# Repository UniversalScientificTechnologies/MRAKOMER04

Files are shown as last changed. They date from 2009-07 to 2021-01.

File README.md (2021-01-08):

# MRAKOMER04B (MRAKOMER 4.0 equivalent)

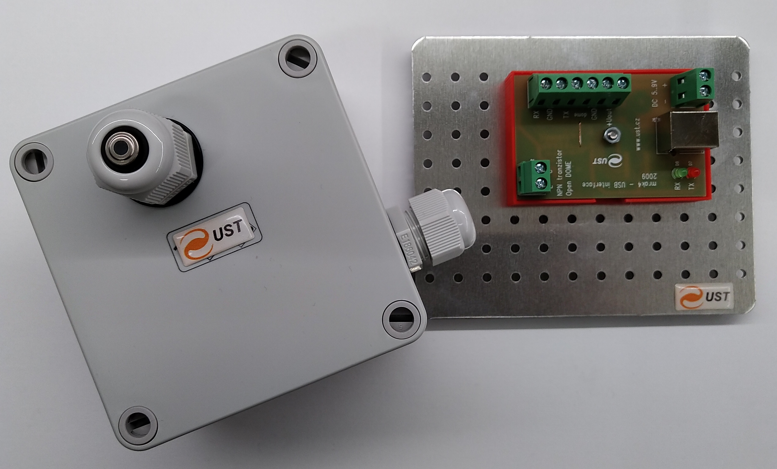
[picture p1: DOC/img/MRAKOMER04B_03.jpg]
Set of MRAKOMER04 internal and outdoor units


### Documentation:

  - [Czech](/DOC/MRAKOMER04B.cs.pdf)
  - [English](/DOC/MRAKOMER04B.en.pdf)

### Parameters:

  - Temperature measurement accuracy 1 °C  
  - Dual zone measurement in FOV 40 deg for each zone
  - Measurement period 1 second
  - Measurement temperature range -65 to +40 °C
  - Operating temperature range -30 to +40 °C

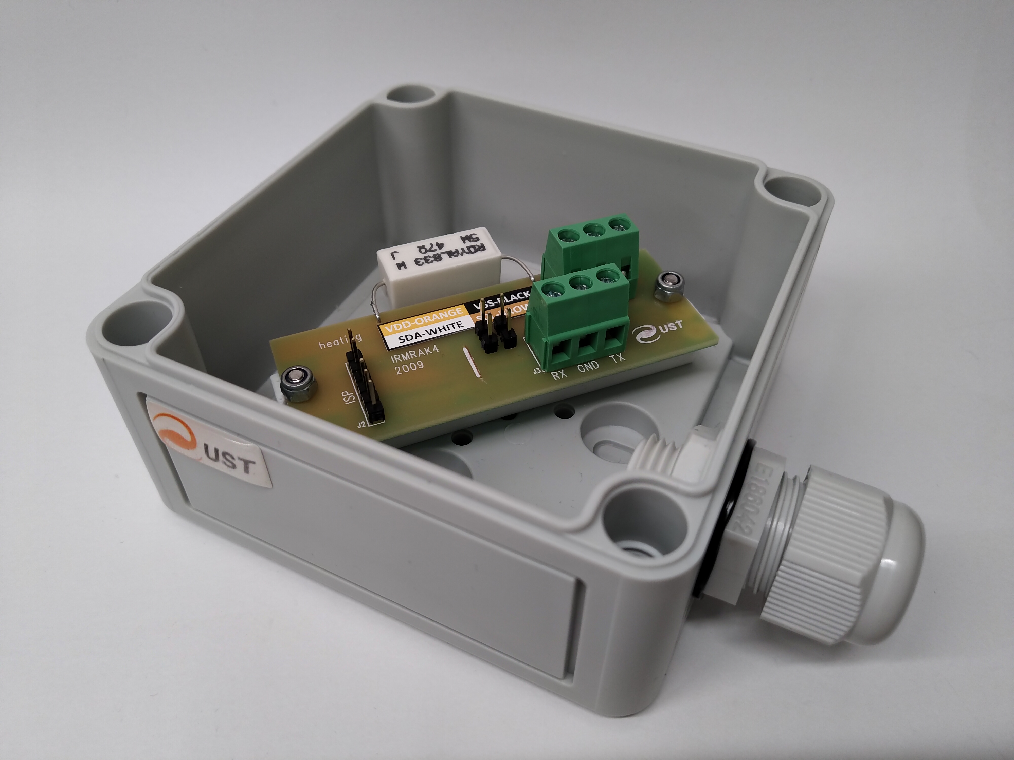
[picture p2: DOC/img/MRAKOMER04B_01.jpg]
MRAKOMER04 external unit opened


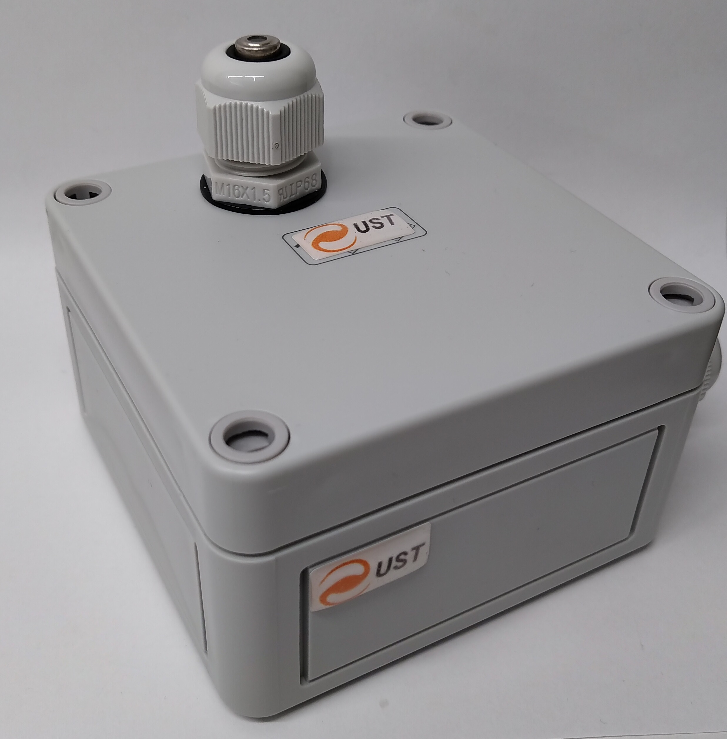
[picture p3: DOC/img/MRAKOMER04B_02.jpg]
MRAKOMER04 external unit


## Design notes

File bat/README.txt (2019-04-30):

h.sh -- heating activation
logger.sh -- simple logging script 
plotMM.plt -- gnuplot data plot script
uf_new.sh -- firmware upload script for new MRAKOMER4 only with bootloader
uf_upload.sh -- firmware upload script

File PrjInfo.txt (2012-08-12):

//
// This is a project description file.
//

[InfoShortDescription.en]
Mrakoměr4 (Clouds sensor) 

[InfoShortDescription.cs]
Mrakoměr4
  
[InfoLongDescription.en]
This is a device for measurement the clouds coverage. This device is especially constructed for protection of robotics telescopes against rain and snow. This is a second generation without moving parts.

[InfoLongDescription.cs]
Přístroj je navržen pro detekci kritického lokálního množství vody v atmosféře jako součást robotických dalekohledů. Tento model je druhou vylepšenou generací bez pohyblivých částí.

[InfoBuyUST]
http://www.ust.cz/shop/product_info.php?cPath=29&products_id=43

[End]

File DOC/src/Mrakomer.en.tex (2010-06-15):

\documentclass[10pt,a4paper]{article}
\usepackage[utf8]{inputenc}
\usepackage[english]{babel}
\usepackage{graphicx}
\usepackage{amsmath}
\usepackage{amsfonts}
\usepackage{amssymb}
%\usepackage{fancyhdr}

%\pagestyle{fancy}
%\fancyhead{}
%\fancyfoot{}

\title{MRAKOMĚR}
\author{Kaklik}

%\fancyhead[C]{\begin{tabular}\hline \title nejaky text \hline \end{tabular}}
%\fancyfoot[L] {/\today / \author / www.mlab.cz}
%\fancyfoot[R]{\thepage }

\begin{document}

\maketitle
\tableofcontents

\newpage

\section{Why you need the MRAKOMĚR?}
MRAKOMĚR is a cloud meter sensor suitable for protect maintenance free telescopes against rain and snow. The MRAKOMĚR function is command cupola or other telescope housing to close if MRAKOMĚR see a cloudy sky. 

\section{Measuring principle}
MRAKOMĚR act as a IR thermometer because clouds reflecting a much IR radiation. Then the measuring unit catch the reflected radiation and count it's intensity to determine how much cloudy sky is above the telescope. If a level of water vapor is over the copula is ordered to close. 

\section{Technical realization}
The thermopile sensor is directed  to the zenith and integrate radiation flux over $90^\circ$ angle. However there must not be any terrestrial (atmospheric  heated) object in viewing  angle because they can cause malfunction by it's IR radiation.        

The thermopile sensor in MRAKOMĚR  is covered by small and thin HDPE cupola which protect the senor itself against atmospheric events. The HDPE material have good transparency in IR but sometimes there can be a condensate water. As solution for this problem (condensate water is resolved as cloudy) there is a 2W heating resistor in MRAKOMĚR case which is suitable to stop water condensing on thermopile sensor housing or it can melt the accidental ice too. 

MRAKOMĚR is connected to telescope computer (IBM PC ) over USB interface  board where is standard RS232 port emulated. Also there is a option of direct RS232 connection if it is desired by user. But in this mode an external power source is needed. And in addition there is an optocoupled output channel which is activated in cloudy or if the computer get frozen.

Sensor and interface part of the MRAKOMĚR is connected together trough  cable connection up to 100m long (the electronics is protected by some transils against damage by electric surge on stormy locations)

\section{Communication protocol}
If MRAKOMĚR is plugged to the computer it communicate by speed 2400 baud (8N1) and every second transmit an message such as: 

\begin{verbatim}
$M4.1 2866 2383 -63 17 15 *5A
\end{verbatim}

Where MX.X is the version and revision 2866 is a number of measuring (0 to 65535). 2383 is a temperature in sensor case (23.83 $^\circ$C). And -63 meaning that sky "have" -0.63 $^\circ$C. Last two numbers before star is number of seconds to turn off the heating and to close the cupola (this counter will resets if appropriate command is received). After a star symbol is hexadecimal value of XOR of symbols between \verb+$+ and *.

\begin{table}[htbp]
\begin{center}
\begin{tabular}{|c|c|}
\hline  h & turn on heating for 20s \\ 
\hline  c & turn off heating  \\ 
\hline  o & open cupola \\ 
\hline  x & open cupola and turn on heating \\ 
\hline  l & close cupola \\ 
\hline  i & list version and some help (only if cupola is closed)  \\ 
\hline  r & turn on periodical messaging every second \\ 
\hline  s & turn off periodical messaging \\ 
\hline  u & switch MRAKOMĚR to firmware update mode \\ 
\hline 
\end{tabular}
\caption{MRAKOMĚR commands}
\end{center}

\end{table}

\section{Conclusions}
MRAKOMĚR is device suitable to perfectly protect telescope. But sometimes may detect cloudy sky even if it clear it is happened when water vapor condensate on sensor housing. It can be prevented by turn on heating if weather conditions is near to condensate point. 

\end{document}

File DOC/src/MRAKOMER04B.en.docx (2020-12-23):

MRAKOMER04B

## MRAKOMER04B is a device for measuring clouds

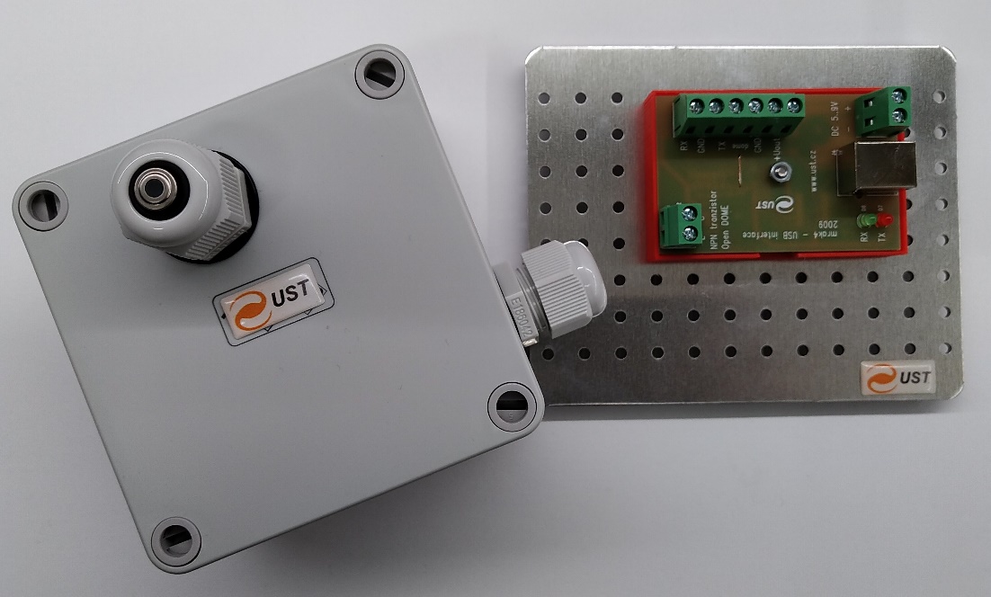
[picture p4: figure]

# 1. Why you need the MRAKOMER04B?

MRAKOMER04B is a cloud meter sensor suitable for protect maintenance free telescopes against rain and snow. The MRAKOMER04B function is command cupola or other telescope housing to close if MRAKOMER04B see a cloudy sky.

# 2. Measuring principle

MRAKOMER04B act as a IR thermometer because clouds reecting a much IR radiation. Then the measuring unit catch the re ected radiation and count it's intensity to determine how much cloudy sky is above the telescope. If a level of water vapor is over the copula is ordered to close.

# 3. Technical realization

The thermopile sensor is directed to the zenith and integrate radiation flux over 90 angle. However there must not be any terrestrial (atmospheric heated) object in viewing angle because they can cause malfunction by it's IR radiation.

The thermopile sensor in MRAKOMER04B is covered by small and thin HDPE cupola which protect the senor itself against atmospheric events. The HDPE material have good transparency in IR but sometimes there can be a condensate water. As solution for this problem (condensate water is resolved as cloudy) there is a 2W heating resistor in MRAKOMER04B case which is suitable to stop water condensing on thermopile sensor housing or it can melt the accidental ice too.

MRAKOMER04B is connected to telescope computer (IBM PC ) over USB interface board where is standard RS232 port emulated. Also there is a option of direct RS232 connection if it is desired by user. But in this mode an external power source is needed. And in addition there is an optocoupled output channel which is activated in cloudy or if the computer get frozen.

Sensor and interface part of the MRAKOMER04B is connected together trough cable connection up to 100m long (the electronics is protected by some transils against damage by electric surge on stormy locations)

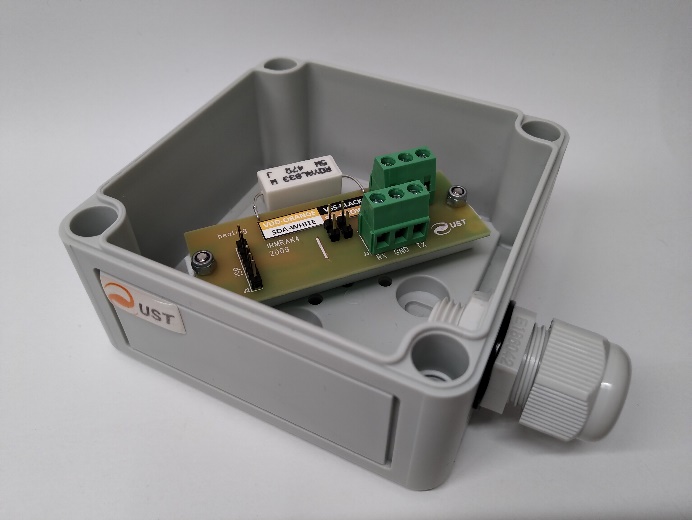
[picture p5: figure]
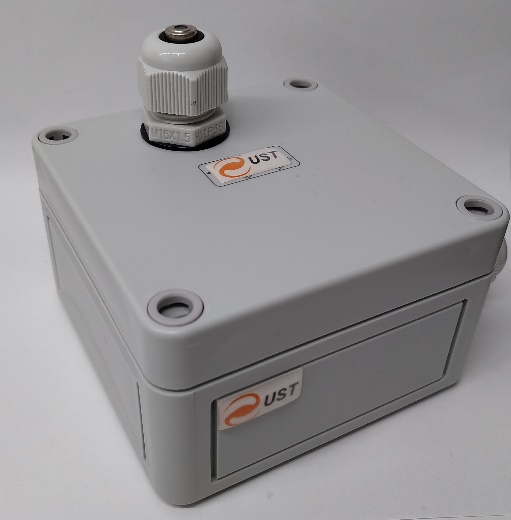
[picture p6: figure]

# 4. Communication protocol

If MRAKOMER04B is plugged to the computer it communicate by speed 2400 baud (8N1) and every second transmit an message such as:

$M4.1 2866 2383 -63 17 15 *5A

Where MX.X is the version and revision 2866 is a number of measuring (0 to 65535). 2383 is a temperature in sensor case (23.83 C). And -63 meaning that sky "have" -0.63 C. Last two numbers before star is number of seconds to turn o the heating and to close the cupola (this counter will resets if appropriate command is received). After a star symbol is hexadecimal value of XOR of symbols between $ and *.

MRAKOMER04B commands:

h turn on heating for 20s

c turn o heating

o open cupola

x open cupola and turn on heating

l close cupola

i list version and some help (only if cupola is closed)

r turn on periodical messaging every second

s turn o periodical messaging

u switch MRAKOMER04B to firmware update mode

# 5. Conclusions

MRAKOMER04B is device suitable to perfectly protect telescope. But sometimes may detect cloudy sky even if it clear it is happened when water vapor con-densate on sensor housing. It can be prevented by turn on heating if weather conditions is near to condensate point.

MRAKOMER04B.en | 2020-12-23 | http://www.ust.cz 1 / 6

www.ust.cz

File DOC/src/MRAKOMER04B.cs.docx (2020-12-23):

MRAKOMER04B

## Mrakoměr je přístroj pro měření oblačnosti.


# 1. Co vlastně mrakoměr měří a proč

Popisované zařízení bylo zkonstruováno pro ochranu robotických bezobslužných dalekohledů před deštěm. Cílem bylo vyvinout přístroj, který bude včas varovat před blížícím se deštěm/sněhem a jeho varování následně vyvolá povel pro zavření domečku dalekohledu. Předpokládá se při tom, že déšť/sníh padá z mraků, které jsou vidět v okolí dalekohledu.

# 2. Princip měření

Mrakoměr je vlastně teploměr, který měří průměrnou teplotu celého sloupce atmosféry. K průměrné teplotě atmosféry nejvíce přispívají nižší husté vrstvy a v nich nejvíce voda, která je obsažena v troposféře. Vzhledem k tomu, že mraky jsou z vody, jejich přítomnost výrazně ovlivňuje průměrnou teplotu.

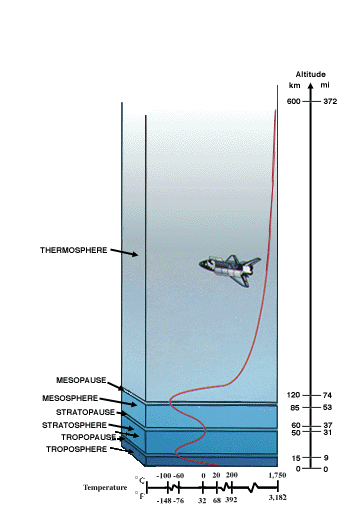
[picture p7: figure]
[Picture of atmosphere layers]

Mrakoměr měří teplotu použitím termoelektrického (Seebeckova) jevu.

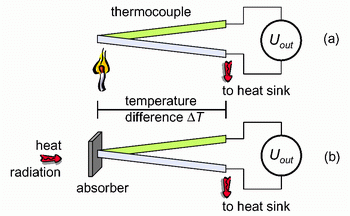
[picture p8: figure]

Spojíme-li dva nesourodé vodiče nebo polovodiče a jeden jejich konec ohříváme a druhý ochlazujeme, vytvoříme článek, který generuje napětí. Pro správné pochopení principu Mrakoměru je důležité si uvědomit, že takovýto článek neměří teplotu, ale tepelný tok.

V Mrakoměru 4 je použit Thermopile senzor. Thermopile senzor je vlastně baterie termočlánků zapojených do série. Teplé konce jsou překryty terčíkem, který absorbuje tepelné záření. Studené konce jsou připojeny na křemíkový nosič. Aby se maximálně snížil přestup tepla křemíkem, je křemíkový nosič ztenčen na tenkou membránu. Teplota křemíku na studeném konci je měřena teplotním senzorem, což umožňuje tepelný tok vztáhnout k absolutní teplotě nosiče a tím určit teplotu dopadajícího IR záření.

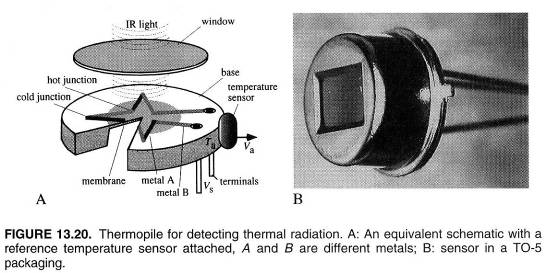
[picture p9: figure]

## 2.1. Popis činnosti

Thermopile senzor se zorným úhlem cca 90° je nasměrován do zenitu a integruje teplotu přes celé zorné pole. Z toho důvodu nesmí být v jeho zorném poli pozemní předměty, jejichž tepelné vyzařování by ovlivňovalo měření.

Thermopile senzor je v Mrakoměru překryt kopulkou z HDPE, která je dobře propustná pro IR záření v okolí 5μm. HDPE je nesmáčivý a tak voda na jeho povrchu v případě deště nebo rosy vytvoří kapky, které pak snadněji opustí zorné pole. Pokud je na kopulce voda, Mrakoměr jí vyhodnotí jako mraky. Uvnitř Mrakoměru je topné těleso o výkonu asi 2W, které slouží k rozpuštění sněhu nebo ledu na kopulce a případně k odpaření rosy.

Mrakoměr se k řídícímu počítači dalekohledu (IBM PC) připojuje pomocí rozhraní USB přes které se provádí emulace RS232. Rozhraní RS232 se používá pro spojení mezi stanicí s thermopile senzorem (horní) a stanicí, kde je převodník mezi USB a RS232 (dolní). Protože rozhraní RS232 umožňuje připojit mezi obě stanice poměrně dlouhé vedení (až 100m) je z tohoto vedení sváděno případné naindukované napětí pomocí transilů.

V dolní stanici je ještě umístěn optočlen, pomocí kterého je možné předat dvoustavový signál z řídícího počítače do zařízení pro otevírání/zavírání kopule dalekohledu. Tento komunikační kanál je díky optočlenu galvanicky oddělen od řídícího systému kopule a je zajištěno, že při poškození Mrakoměru, nebo pokud řídící počítač dalekohledu nepožádá v pravidelném intervalu o otevření kopule, dojde k překlopení do stavu zavřeno.


Pokud se Mrakoměr zapojí do počítače, tak komunikuje rychlostí 2400 baud (8N1) a každou sekundu pošle zprávu, která vypadá například takto:

$M4.1 2866 2383 -63 17 15 *5A

Což znamená:

Verze firmware 4, revize 1. Měření číslo 2866 (opakuje se v rozsahu 0 až 65535); teplota pouzdra 23.83°C; teplota oblohy −0.63°C; 17 znamená, že zbývá 17s do vypnutí topení (0 znamená, že se netopí); 15 znamená 15s do zavření kopule (0 = zavřená kopule). Za * je kontrolní součet znaků mezi $ a * (XOR). Konkrétní hodnoty jsem si zde vymyslel.

Mrakoměr 4 reaguje na tyto příkazy:

h zapne topení na 20s

c vypne topení

o otevře kopuli na 20s

x otevře kopuli a zapne topení, oboje na 20s

l zavře kopuli

i vypíše verzi a nápovědu k výstupu (pouze, pokud je zavřena kopule)

r zapne periodický výpis každou sekundu

s vypne periodický výpis

u update firmware

Pozn.: Je zakázáno posílat do Mrakoměru příkazy častěji, než jednou za 1s. Nic se ale nestane, pokud do něj něco pošlete častěji, ale stejně pak dostanete odpověď na další příkaz až za 1s a navíc si Mrakoměr pamatuje poslední 3 příkazy! Vyzkoušejte si to v terminálu.

Význam LED v dolní stanici/krabičce:

Zelená - něco poslal Mrakoměr do PC (bliká pouze, pokud někdo/něco odebírá data z Mrakoměru, pokud neodebírá, tak bliká pouze do doby, než se zaplní buffery (cca 18 zpráv od Mrakoměru)) Červená - něco poslalo PCčko do Mrakoměru

Na optočlen pro ovládání kopule je možné připojit cokoli, co je na maximálně 300V a 100mA. Když to přeženete, tak optron vyhoří a začnete od píky. Svorkovnice, na kterou se připojuje domeček, je označena, že se na ní připojuje domeček. Pozor na polaritu! GND (zem) není propojena se zemí Mrakoměru. Takže se nemůže nic stát, stát, stát,...

Horní krabičku s čidlem raději nerozebírejte. Pokud ji rozeberete, tak vyjměte pytlík se silikagelem a reaktivujte ho při 150°C.

## 2.2. Update firmware

Mrakoměr 4 umožňuje update jeho firmware, aniž byste ho museli sundat ze střechy. Po zapnutí do USB portu čeká cca 50s na znaky „uf“. Pokud se do té doby do něj pošle něco jiného, začne měřit. Pokud se pošle „uf“, tak očekává HEX soubor s novým firmware. HEX soubor musí být upraven tak, že na konci každé řádky musí být přidán dostatečný počet (cca 20) výplňových znaků (např. „x“), které poskytnou Mrakoměru čas na vypálení jedné řádky kódu. Je to z důvodu, aby se nemusel používat v komunikaci handshake nebo specielní software pro výměnu firmware. Takto se dá nový firmware nahrát z terminálu a to i na dálku. Pokud se nový firmware nepodaří nahrát, je sice starý firmware přepsán a nefunguje, ale Mrakoměr opět bude čekat na znaky „uf“ a umožní vám nový pokus o přepsání firmware. Pokud odstraníte chybu (ta bude zřejmě ve vašem programu) a dáte na modlení, tak se vám podaří nahrát nový firmware.

## 2.3. Dosažené výsledky a omezení konstrukce

Popisované řešení dokáže spolehlivě detekovat oblačnost. Může se ovšem stát, že dojde k falešné detekci, pokud je stav okolního vzduchu blízký rosnému bodu a na kopulce zkondenzuje voda. Tomuto jevu můžeme předejít včasnou aktivací vyhřívání Mrakoměru.

Mrakoměr byl vyvinut pro potřeby dalekohledů s řídícím systémem RTS2. Proto jeho firmware funguje tak, jak funguje.

Mrakoměr je „Open Hardware“. To znamená, že je k dispozici plně dokumentované elektrické zapojení, výkresy plošných spojů a zdrojové kódy firmware. Můžete si tedy Mrakoměr sami vyrobit nebo dle libosti upravit To neznamená, že vám ho nepomůžeme vyrobit nebo pro vás neuděláme vylepšení, která budete potřebovat, když nás poprosíte, ovšem to už za peníze (to by nám jinak doma neprošlo ).

MRAKOMER04B.cs | 2020-12-23 | http://www.ust.cz 1 / 6

www.ust.cz

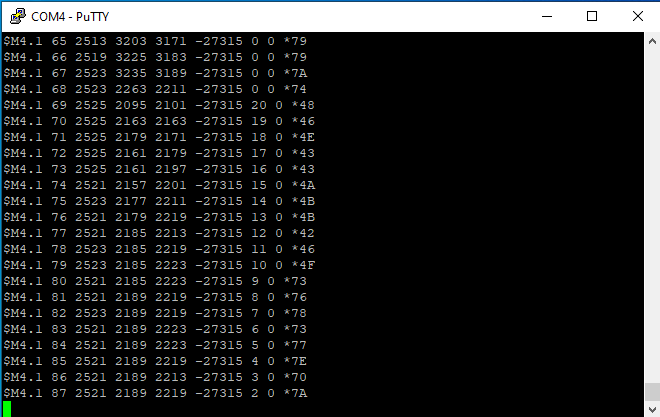
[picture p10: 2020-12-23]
DOC/img/MRAKOMER04B_RS_vypis.png

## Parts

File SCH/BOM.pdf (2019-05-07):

seznam součástek USB_PART_IRMRAK4 , IRMRAK4

USB_PART_IRMRAK4

Quantity | Reference | Part | PCB Footprint

kondenzátory
| 2 C1,C2 | 1u | C0805
| 8 C3,C5,C6,C7,C8,C9,C10,C11 | 100nF | C0805
| 1 C4 | 10uF/10V | C0805
diody
| 1 D1 | BAR43SSMD | SOT23
| 1 D2 | 15MQ040N | SMB
4 D3,D4,D5,D6 | P6SMBJ15CA (obousmerny) SMB
1 D7 | LED3mm_RED | 01. 03
1 D8 | LED3mm_GREEN | 01. 03
mechanika
| 1 J1 | LOAD_POWER | ARK210/2
| 1 J2 | DOME | ARK210/2
| 1 J3 | POWER | ARK210/3
| 1 J4 | USB_B_01 | USB_B_01
| 1 J5 | RS232 | ARK210/3
| 4 M1 | HOLE_M3 | HOLE_M3
optočlen
| 1 Q1 | TLP127-SMD | MFSOP6
tranzistory
| 1 Q2 | BC817SMD | SOT23
odpory
| 1 R1 | 150 | R0805
| 1 R2 | 180 | R0805
| 2 R5,R3 | 10k | R0805
| 1 R4 | 4k7 | R0805
| 2 R6,R7 | 270 | R0805
IO
| 1 U1 | FT232RL | SSO28_210
| 1 U2 | MAX232SMD/ST232ACD | SO16_150

IRMRAK4

Quantity | Reference | Part | PCB Footprint

kondenzátory
9 C1,C2,C3,C4,C5,C6,C7,C9,C11 100nF | C0805
| 1 C8 | 10u/16V | ELYTB
| 1 C10 | 10u/10V_tantal | ELYTA
diody
4 D1,D2,D3,D5 | P6SMBJ15CA (obousmerny) SMB
| 1 D4 | 15MQ040N | SMB
mechanika
| 1 J2 | PIC_ISP | PIC_ISP
| 1 J3 | RS232 | ARK210/3
| 1 J4 | POWER | ARK210/3

2 M2,M1 | HOLE_M3 | HOLE_M3
tranzistor
1 Q1 | IRF7413SMD | SO8_FET
rezistory
3 R1,R3,R4 | 100 | R0805 1 R2 | 47/5W (9V) 12R/5W pro 5V R5W 2 R7,R6 | 10k | R0805

IO
1 U1 | MAX232SMD/ST232ACD | SO16_150 1 U2 | PIC16LF88_SO18 | SO18_300 1 U3 | LE33CD_SO8 | SO8_150 1 U4 | MLX90614_TO39 | TO39_4

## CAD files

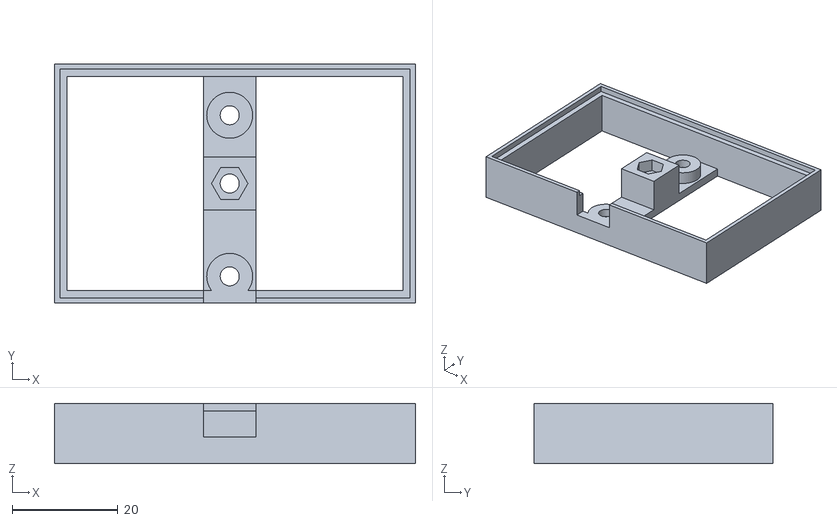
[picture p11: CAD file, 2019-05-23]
CAD/MRAKOMER4_HOLDER01A/amf/P_MRAKOMER4_HOLDER03A.stl
68.3 x 45.3 x 11.4

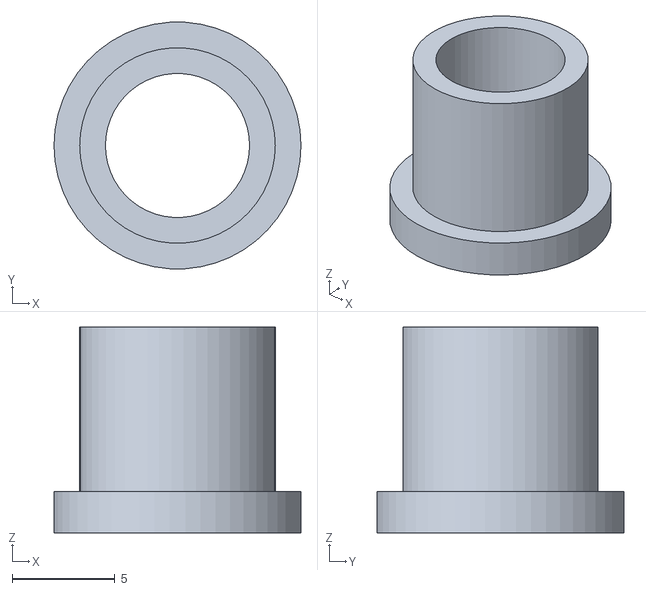
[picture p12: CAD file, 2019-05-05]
CAD/MRAKOMER4_HOLDER01A/amf/P_MRAKOMER4_HOLDER02B.stl
12.0 x 12.0 x 10.0

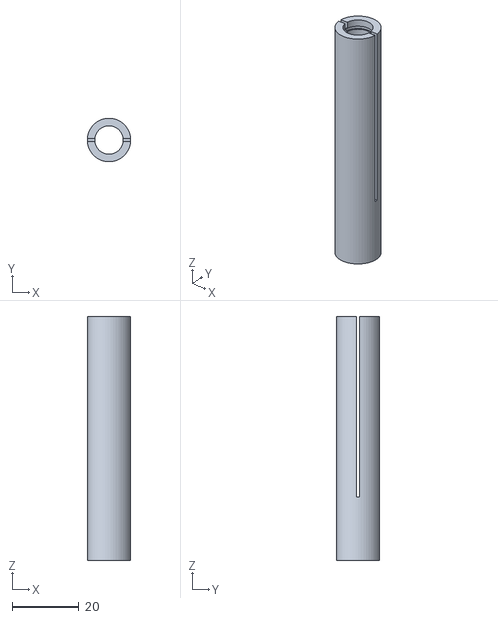
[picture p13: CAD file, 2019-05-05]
CAD/MRAKOMER4_HOLDER01A/amf/P_MRAKOMER4_HOLDER02A.stl
13.0 x 13.0 x 73.0

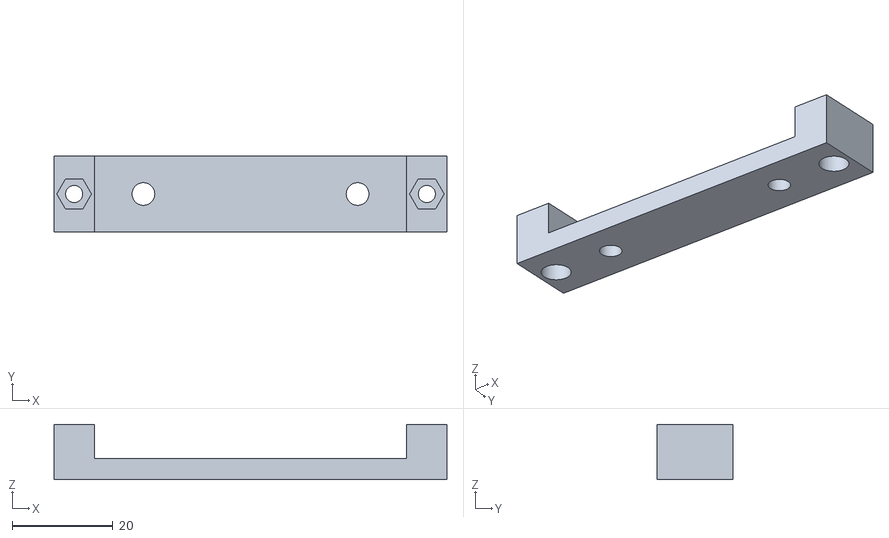
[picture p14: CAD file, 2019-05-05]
CAD/MRAKOMER4_HOLDER01A/amf/P_MRAKOMER4_HOLDER01A.stl
78.0 x 15.0 x 11.0

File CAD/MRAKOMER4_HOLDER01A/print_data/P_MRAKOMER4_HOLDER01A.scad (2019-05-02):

use <../src/MRAKOMER4_HOLDER01A.scad>

$fn=50;

MRAKOMER4_HOLDER01A();

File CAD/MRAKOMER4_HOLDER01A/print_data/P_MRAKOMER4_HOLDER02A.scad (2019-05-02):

use <../src/MRAKOMER4_HOLDER02A.scad>

$fn=50;

MRAKOMER4_HOLDER02A();

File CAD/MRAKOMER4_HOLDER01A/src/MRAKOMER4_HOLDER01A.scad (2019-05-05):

$fn=50;
//otvory v krabičce
uchyt_roztec=42.5;
uchyt_prumer=4.5;


//otvordy pro PCB mrakomeru
PCB_prumer=3.4;
PCB_roztec=70;
PCB_vyska_soucastek=7;

vyska_materialu=4;
sire_materialu=15;


M3_vyska_matky=3;
M3_sirka_matky=6.7;
M3_prumer_hlavy_sroubu=6;
M3_vyska_hlavy=5;

//sloupek
sloupek_sirka=8;



MRAKOMER4_HOLDER01A();

module MRAKOMER4_HOLDER01A()
{
difference() {
    
union() { 

translate([0,0,vyska_materialu/2]) 
minkowski()
{
  cube([uchyt_roztec+uchyt_prumer,sire_materialu-8,vyska_materialu],center=true);
  cylinder(r=4,h=0.1);
}

translate([0,0,vyska_materialu/2+0.1]) 
  cube([PCB_roztec+PCB_prumer,sire_materialu,vyska_materialu+0.2],center=true);
  


translate([PCB_roztec/2,0,0]) 
SLOUPEK();  

translate([-PCB_roztec/2,0,0]) 
SLOUPEK(); 

}
   

//otvory pro uchycení PCB
translate([PCB_roztec/2,0,vyska_materialu/2]) 
cylinder(h=vyska_materialu+052, r=PCB_prumer/2, center=true);

translate([PCB_roztec/2,0,M3_vyska_hlavy/2])   
     cylinder(h=M3_vyska_hlavy, r=M3_prumer_hlavy_sroubu/2, center=true);

translate([-PCB_roztec/2,0,vyska_materialu/2]) 
cylinder(h=vyska_materialu+0.5, r=PCB_prumer/2, center=true);

translate([-PCB_roztec/2,0,M3_vyska_hlavy/2])   
     cylinder(h=M3_vyska_hlavy, r=M3_prumer_hlavy_sroubu/2, center=true);

//otvory pro uchycení ke krabičce
translate([uchyt_roztec/2,0,vyska_materialu/2]) 
cylinder(h=vyska_materialu+0.5, r=uchyt_prumer/2, center=true);

translate([-uchyt_roztec/2,0,vyska_materialu/2]) 
cylinder(h=vyska_materialu+0.5, r=uchyt_prumer/2, center=true);


    
    }
   }
  
   
  
    
 module SLOUPEK()  
   {
 
   difference() {
       translate([0,0,(vyska_materialu+PCB_vyska_soucastek)/2])   
    cube([sloupek_sirka,sire_materialu,vyska_materialu+PCB_vyska_soucastek],center=true);   
     
     
     translate([0,0,vyska_materialu+PCB_vyska_soucastek-M3_vyska_matky])    
    cylinder (h = M3_vyska_matky+0.01, r= (M3_sirka_matky+0.2)/2, $fn=6); 
     
         translate([0,0,(vyska_materialu+PCB_vyska_soucastek)/2])   
     cylinder(h=vyska_materialu+PCB_vyska_soucastek+0.2, r=PCB_prumer/2, center=true);
     
      translate([0,0,M3_vyska_hlavy/2])   
     cylinder(h=M3_vyska_hlavy, r=M3_prumer_hlavy_sroubu/2, center=true);
     
     
      
       
    }   
  }   
        

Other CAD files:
CAD/MRAKOMER4_HOLDER01A/src/MRAKOMER4_HOLDER02A.scad
CAD/MRAKOMER4_HOLDER01A/src/MRAKOMER4_HOLDER03A.scad

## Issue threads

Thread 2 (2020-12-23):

Vylepšení

ChroustJan, 2020-12-23:
Opravit odmaskovani propojek
Pridat venkovni teplomer
Pridat bezpecnostni cidlo na prunik vlhkosti.
Pridat ochranny odpor do Gate spinaciho tranzistoru pro topeni.

Unekterych mrakomeru zaznamenan problem se smazanim Firmwaru s variantou PIC16F88 (ne LF na 3,3V)

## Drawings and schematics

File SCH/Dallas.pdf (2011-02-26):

## IRMRAK

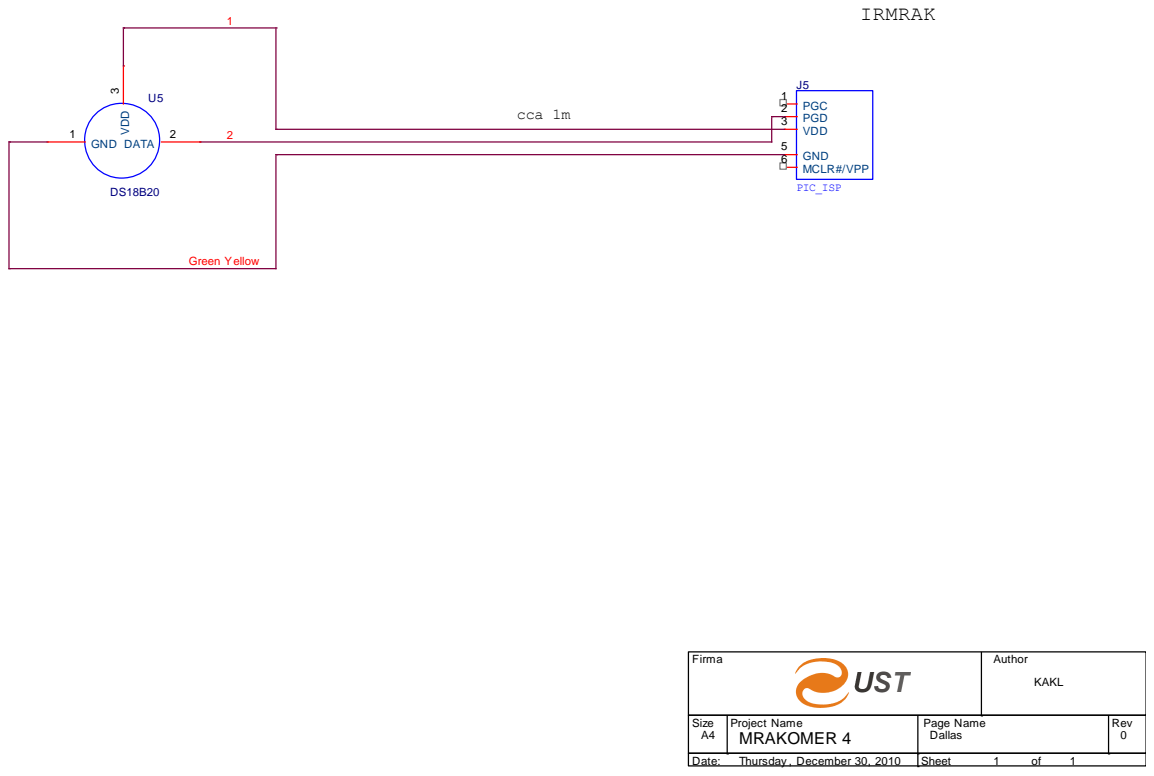
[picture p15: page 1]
PIC_ISP; PGC; PGD; VDD; GND; MCLR#/VPP; Size; Project Name; Rev; Date:; Page Name; Sheet; Firma; Author; Dallas; Thursday , December 30, 2010; MRAKOMER 4; KAKL; Green Yellow; DATA VDD; cca 1m

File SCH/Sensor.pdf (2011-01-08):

# 8 VCC ¹⁶ GND 15

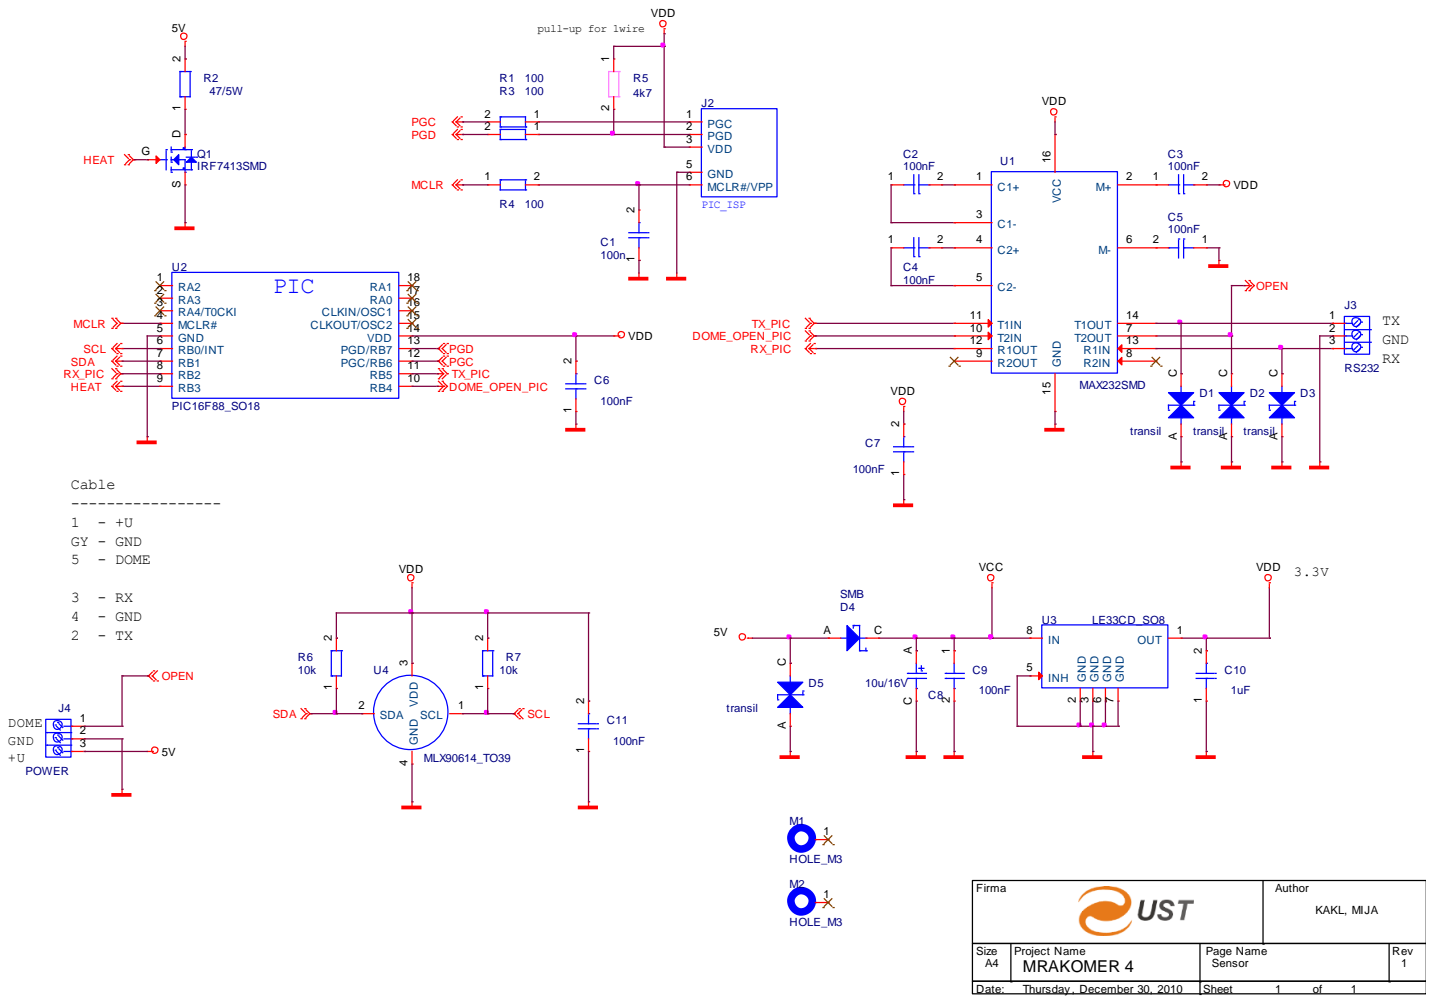
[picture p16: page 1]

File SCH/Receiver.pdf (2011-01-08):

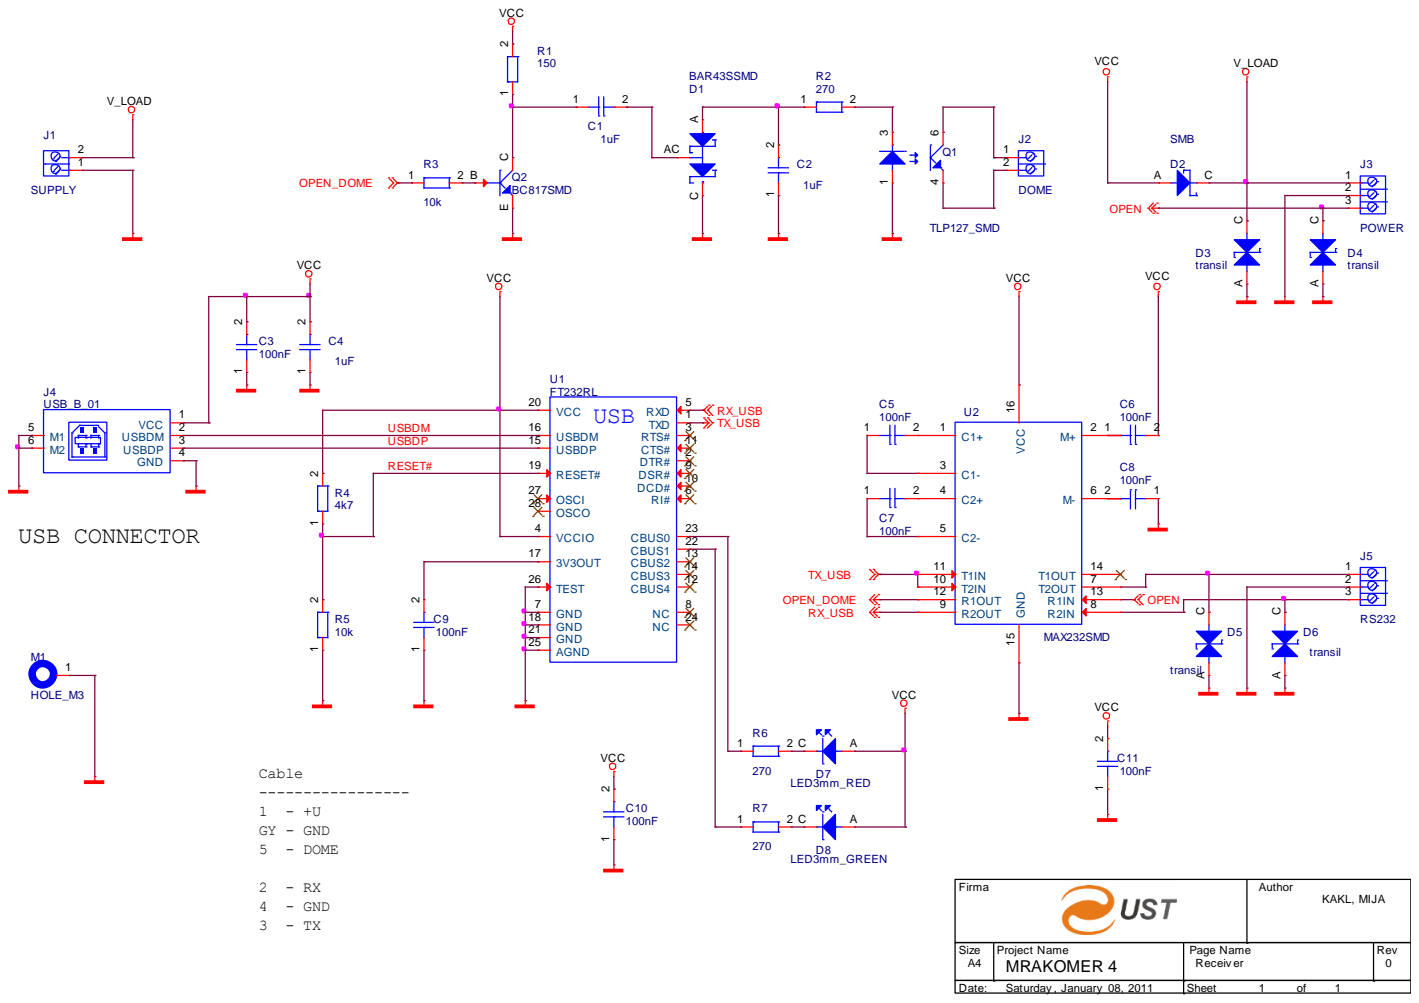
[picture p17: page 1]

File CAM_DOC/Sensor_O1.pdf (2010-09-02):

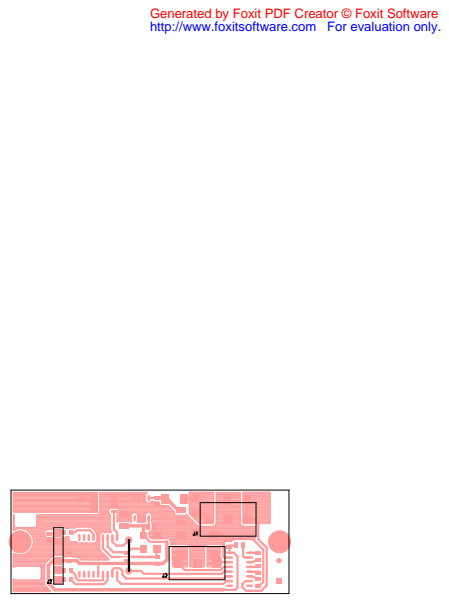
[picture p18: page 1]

Generated by Foxit PDF Creator © Foxit Software
http://www.foxitsoftware.com For evaluation only.

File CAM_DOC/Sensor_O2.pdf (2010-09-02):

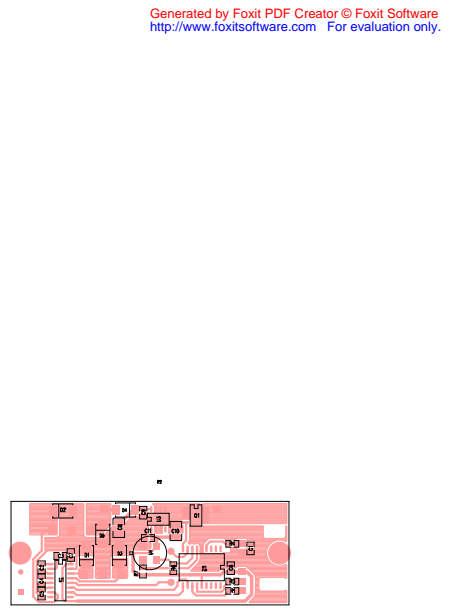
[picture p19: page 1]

Generated by Foxit PDF Creator © Foxit Software
http://www.foxitsoftware.com For evaluation only.

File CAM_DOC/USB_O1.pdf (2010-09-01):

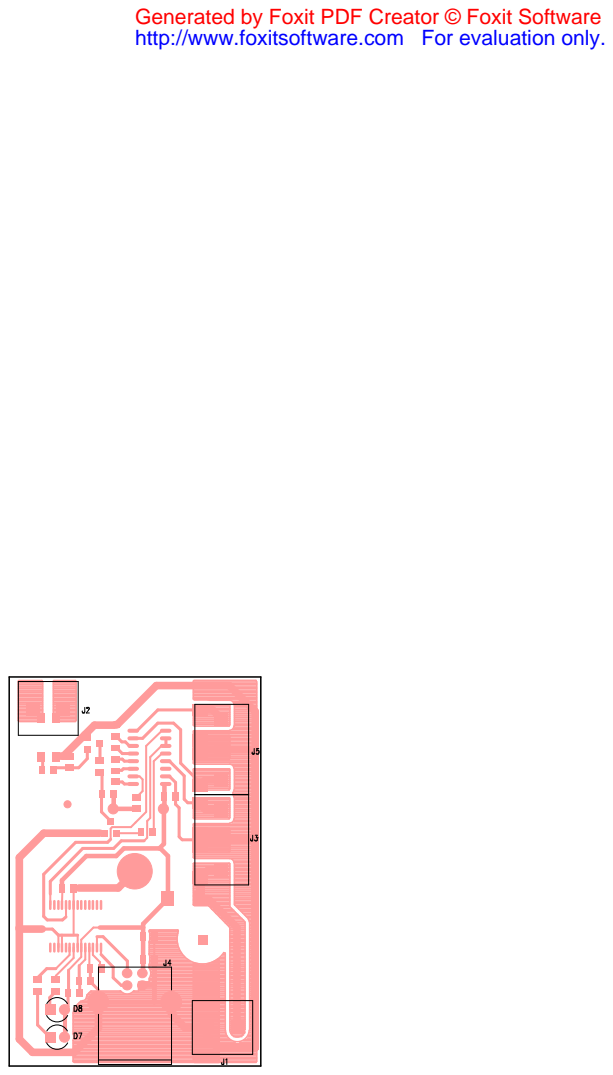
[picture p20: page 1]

Generated by Foxit PDF Creator © Foxit Software
http://www.foxitsoftware.com For evaluation only.

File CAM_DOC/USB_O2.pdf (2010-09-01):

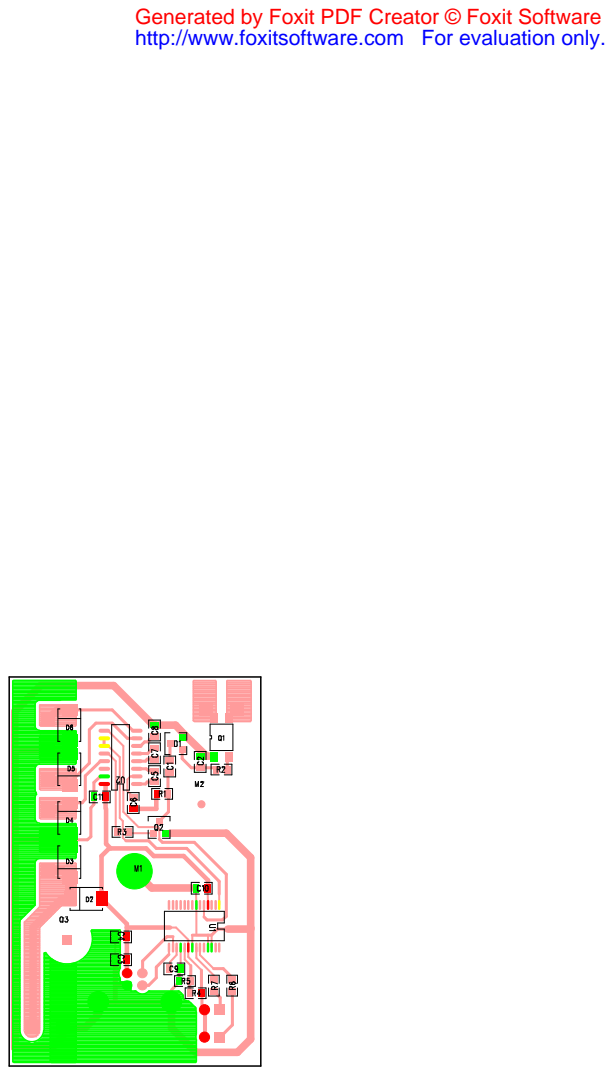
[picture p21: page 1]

Generated by Foxit PDF Creator © Foxit Software
http://www.foxitsoftware.com For evaluation only.

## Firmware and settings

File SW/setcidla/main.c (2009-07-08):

#include "main.h"
#include "string.h"

#define  SA          0x00     // Slave Address (0 for single slave / 0x5A<<1 default)
#define  EEPROM_Access  0x20     // EEPROM access command
#define  EEPROM_Addr 0x0E     // I2CAddr address in the eeprom
#define  RAM_Access  0x00     // RAM access command
#define  RAM_Tobj1   0x07     // To1 address in the ram
#define  RAM_Tamb    0x06     // Ta address in the ram
#define  MAXHEAT     60       // Number of cycles for heating


BYTE gethex1() {
   char digit;

   digit = getc();

   putc(digit);

   if(digit<='9')
     return(digit-'0');
   else
     return((toupper(digit)-'A')+10);
}

BYTE gethex() {
   unsigned int8 lo,hi;

   hi = gethex1();
   lo = gethex1();
   if(lo==0xdd)
     return(hi);
   else
     return( hi*16+lo );
}

int16 sonar_ping (int8 addr)
{
   int16 distance;
   int8 pom;

   i2c_start();     // So Sonar Ping
   i2c_write(addr);
   i2c_write(0x0);
   i2c_write(0x51);  // 50 mereni v palcich, 51 mereni v cm, 52 v us
   i2c_stop();
   delay_ms(70);
   i2c_start();     // Read Reflection
   i2c_write(addr);
   i2c_write(0x2);
   i2c_stop();
   i2c_start();
   i2c_write(addr+1);
   pom=i2c_read(1);
   distance=MAKE16(pom,i2c_read(0));
   i2c_stop();

   return distance;
}

unsigned char PEC_calculation(unsigned char pec[]) // CRC calculation
{
   unsigned char   crc[6];
   unsigned char   BitPosition=47;
   unsigned char   shift;
   unsigned char   i;
   unsigned char   j;
   unsigned char   temp;

   do
   {
      crc[5]=0;            /* Load CRC value 0x000000000107 */
      crc[4]=0;
      crc[3]=0;
      crc[2]=0;
      crc[1]=0x01;
      crc[0]=0x07;
      BitPosition=47;         /* Set maximum bit position at 47 */
      shift=0;

      //Find first 1 in the transmited message
      i=5;               /* Set highest index */
      j=0;
      while((pec[i]&(0x80>>j))==0 && i>0)
      {
         BitPosition--;
         if(j<7)
         {
            j++;
         }
         else
         {
            j=0x00;
            i--;
         }
      }/*End of while */

      shift=BitPosition-8;   /*Get shift value for crc value*/


      //Shift crc value
      while(shift)
      {
         for(i=5; i<0xFF; i--)
         {
            if((crc[i-1]&0x80) && (i>0))
            {
               temp=1;
            }
            else
            {
               temp=0;
            }
            crc[i]<<=1;
            crc[i]+=temp;
         }/*End of for*/
         shift--;
      }/*End of while*/

      //Exclusive OR between pec and crc
      for(i=0; i<=5; i++)
      {
         pec[i] ^=crc[i];
      }/*End of for*/
   } while(BitPosition>8);/*End of do-while*/

   return pec[0];
}/*End of PEC_calculation*/

int16 ReadTemp(int8 addr, int8 select)    // Read sensor RAM
{
   unsigned char arr[6];         // Buffer for the sent bytes
   int8 crc;                     // Readed CRC
   int16 temp;                   // Readed temperature

   i2c_stop();
   i2c_start();
   i2c_write(addr);
   i2c_write(RAM_Access|select);  // Select the teperature sensor in device
   i2c_start();
   i2c_write(addr);
   arr[2]=i2c_read(1);        // lo
   arr[1]=i2c_read(1);        // hi
   temp=MAKE16(arr[1],arr[2]);
   crc=i2c_read(0);           //crc
   i2c_stop();

   arr[5]=addr;
   arr[4]=RAM_Access|select;
   arr[3]=addr;
   arr[0]=0;
   if (crc != PEC_calculation(arr)) temp=0; // Calculate and check CRC

   return temp;
}

int16 ReadEeprom(int8 addr, int8 select)
{
   unsigned char arr[6];         // Buffer for the sent bytes
   int8 crc;                     // Readed CRC
   int16 temp;                   // Readed temperature

   i2c_stop();
   i2c_start();
   i2c_write(addr);
   i2c_write(EEPROM_Access|select);  // Select the teperature sensor in device
   i2c_start();
   i2c_write(addr);
   arr[2]=i2c_read(1);        // lo
   arr[1]=i2c_read(1);        // hi
   temp=MAKE16(arr[1],arr[2]);
   crc=i2c_read(0);           //crc
   i2c_stop();

   arr[5]=addr;
   arr[4]=EEPROM_Access|select;
   arr[3]=addr;
   arr[0]=0;
   if (crc != PEC_calculation(arr)) temp=0; // Calculate and check CRC

   return temp;
}

void WriteEeprom(int8 addr, int8 select, int16 value)
{
   unsigned char arr[6];         // Buffer for the sent bytes
   byte crc,hi,lo;

   hi=MAKE8(value,1);
   lo=MAKE8(value,0);

   arr[0]=0;
   arr[1]=hi;
   arr[2]=lo;
   arr[3]=EEPROM_Access|select;
   arr[4]=addr;
   arr[5]=0;

   crc=PEC_calculation(arr);

   i2c_stop();
   i2c_start();
   i2c_write(addr);
   i2c_write(EEPROM_Access|select);
   i2c_write(lo);
   i2c_write(hi);
   i2c_write(crc);
   i2c_stop();

   printf("CRC: %X \n\r",crc);
}

void setadresstemp()
{
   int newaddr=0;

   printf("Zadej adresu (Hex):");
   newaddr=gethex();
   putc('\n');
   putc('\r');

   WriteEeprom(SA,EEPROM_Addr,0);
   delay_ms(8);
   WriteEeprom(SA,EEPROM_Addr,newaddr);
   delay_ms(8);
}

void main()
{
   char c;
   unsigned int16 temp, tempa;
   signed int16 ta, to;
   byte addr, addr_new;

   setup_adc_ports(NO_ANALOGS);
   setup_adc(ADC_OFF);
//   setup_psp(PSP_DISABLED);
   setup_timer_0(RTCC_INTERNAL|RTCC_DIV_1);
   setup_timer_1(T1_DISABLED);
   setup_timer_2(T2_DISABLED, 0, 1);
   setup_oscillator(OSC_4MHZ|OSC_INTRC);

   delay_ms(100);

   printf("\n\r SETCIDLA - Martin Poviser 2008 \n\r");

   while(true)
   {
      printf("k - zapsani adresy do teplotniho cidla\n\r");
      printf("o - precteni adresy teplotniho cidla\n\r");
      printf("r - precteni teploty teplotniho cidla\n\r");
      printf("t - precteni teploty teplotniho cidla z adresy 0\n\r");
      printf("s - precteni vzdalenosti ze sonaru\n\r");
      printf("c - zmena adresy sonaru\n\r");
      printf("?");
      c=getc();
      putc('\n');
      putc('\r');

      switch(c)
      {
         case 'k':
               setadresstemp();
            break;

         case 'r':
               printf("Zadej adresu (Hex):");
               addr=gethex()<<1;
               putc('\n');
               putc('\r');

               tempa=ReadTemp(addr, RAM_Tamb);       // Read temperatures from sensor
               temp=ReadTemp(addr, RAM_Tobj1);

               to=(signed int16)(temp*2-27315);
               ta=(signed int16)(tempa*2-27315);

               printf("-- %.2g %.2g \n\r",(float)ta/100,(float)to/100);
            break;

         case 't':
               while(!kbhit())
               {
                  tempa=ReadTemp(0, RAM_Tamb);       // Read temperatures from sensor
                  temp=ReadTemp(0, RAM_Tobj1);
   
                  to=(signed int16)(temp*2-27315);
                  ta=(signed int16)(tempa*2-27315);
   
                  printf("-- %.2g %.2g %.2g\n\r",(float)ta/100,(float)to/100, (float)(ta-to)/100);
               delay_ms(1100);
               };
               getc();
            break;

         case 'o':
               printf("Adresa: %X \n\r",ReadEeprom(SA,EEPROM_Addr));
            break;

         case 's':
               printf("Zadej adresu (Hex):");
               addr=gethex();
               putc('\n');
               putc('\r');

               printf("Distance [cm]: %Lu \n\r", sonar_ping(addr));
            break;

         case 'c':
               printf("Zadej starou adresu (Hex):");
               addr=gethex();
               putc('\n');
               putc('\r');
               printf("Zadej novou adresu (Hex):");
               addr_new=gethex();
               putc('\n');
               putc('\r');

               i2c_start();
               i2c_write(addr);
               i2c_write(0x0);
               i2c_write(0xA0);  // Change address sequence
               i2c_stop();

               i2c_start();
               i2c_write(addr);
               i2c_write(0x0);
               i2c_write(0xAA);  // Change address sequence
               i2c_stop();

               i2c_start();
               i2c_write(addr);
               i2c_write(0x0);
               i2c_write(0xA5);  // Change address sequence
               i2c_stop();

               i2c_start();
               i2c_write(addr);
               i2c_write(0x0);
               i2c_write(addr_new);  // New address
               i2c_stop();
            break;
      }
   }
}

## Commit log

2013-07-30 oprava/úprava modulu, přidány gerber data pro potisk bootom, odstranění potisku top.
2013-07-30 úprava PCB (zarovnání + zvětšení textu top, přidání prokovů, odstranění Couper Out u pinu na anténu) vygenerování nových gerber dat
2013-07-30 datasheet k ochranne diode.
2013-08-02 Pridani seznamu soucastek pro ADC zapojeny pred ARMem
2013-08-02 popisek k zapojeni zesilovace pred ADC u ARM.
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2013-09-16 ulozeni udaju k převodníku na I2C
2013-09-19 pridani dat z experimentu se sonarem.
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2013-09-28 presunuti cteni ADC a regulacni smycky do interruptu
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2013-09-28 nastartovani adc na zacatku behu programu
2013-09-29 pokus s rozfungovanim cteni z obecneho driveru HID.
2013-09-29 Upravený příklad Ethernetu na STM32 od ST.
2013-10-05 fungujici konstrukce z i2c-avr-usb
2013-11-10 reseni problemu s realizaci I2C meteostanice.
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2013-12-02 testovaci program pro vycitani mereni ze sensoru.
2013-12-23 zalozeni nove dokumentacni slozky pro dvoukanalovy ADC.
2014-01-05 Hodinový PLL generátor s obvodem TI CDCE913 (schema, PCB a technologické výstupy).
2014-01-09 Opraven SCH a PCB CLK1PLL01A (oprava EN vývodů u stabilizátorů), nutno ještě přegenerovat PDF výstupy od plošného spoje (zde PDF995 generuje velmi nekvalitní výstupy, nutno použít něco funkčnějšího).
2014-02-04 ve firmwaru AWS odstranen aktualni cas. Je overena funkce i2c slave. Je treba doplnit relativni casove mereni. A aktualizaci registru.
2014-02-08 Nový modul AVRUSB01A pro SW realizaci USB na AVR, umí ISP programování, nebo USB na I2C
2014-02-15 Doladěny přepínače FUSE pro procesory ATmega8 a ATmega88
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2014-02-26 pridani navrhu v KiCAD.
2014-03-02 Původní verze firmwaru (pro referenci změn) i2c-tiny-usb pro modul AVRUSB01
2014-03-02 Upravená verze firmwaru i2c-tini-usb pro modul AVRUSB01
2014-03-02 Překlad firmwaru I2C pro AVRUSB01 (plus oprava pro překlad pod Linuxem)
2014-03-06 aktualizace kodu pro novou verzi I2C knihoven.
2014-03-10 pridani navrhu differencniho vstupu pro adc ve zvukovce.
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2014-03-16 dokoncovani navrhu plosneho spoje pro FMC redukci (pridany koty). Zacatek navrhu modulu pro ADC.
2014-03-18 prvni optimalizace differencnich spoju. A prohozeni polarity vstupu ADC.
2014-03-19 pridani zapomenutych souboru a uprava skriptu pro prejmenovani vystupu z KiCADu.
2014-03-24 Added an utility for setting Si570 without frequency measurement. Factory calibration is used.
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2014-04-08 Přidána podpora jak společné anody tak i společné katody LED displeje.
2014-04-17 rozdeleni konstrukce AWS01B na novou vyvojovou vetev AWS02A, ktera se uz nepripojuje pres RS323, ale pres I2C.
2014-04-24 Uprava kodu pro puziti s Odroidem a I2C hubem.
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2015-01-02 oprava chyby - misto pro kondenzatory na redukcnim PCB.
2015-01-11 zlepšeny tolerance PCB.
2015-01-16 editace podlozky pro lepsi geometrii a usetreni materialu.
2015-02-03 zlepseni dokumentace. Pokus o vytvoreni sablony KiCAD, ktera by umoznila kresleni plosnych spoju v prvnim kvadrantu.
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2015-03-06 zaroutovani casti PCB po posunuti der a okraje
2015-03-11 zmena pouzder u kondenzatoru a diod.
    V teto verzi je taky omylem aktualizovany footprint pro 2mm hrebinek, coz zpusobilo problem diky zmene cislovani.
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2015-05-04 upravy popisku a cest pro lepsi vedeni GND.
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2015-06-19 shorten LED blink
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2015-09-15 Posunuti PCB do stredu stranky pri tisk dokumentace.
2015-09-18 zacatek navrhu noveho PCB pro modul vykonoveho zesilovace.
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2015-10-08 LCD holder for box and BaseBoard case modification
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2015-10-15 upraveni dat pro BASEBOX01A. Tiskova data budou ve slozce print_data
2015-11-03 New setup for LION2CELL. Do not go properly. Capacyty decreased with charging and increased with discharging.
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2015-11-25 vracena hodnota PWM frekvence na tovarni hodnotu, aby nebylo slyset piskani vinuti.
2015-11-26 First moving with right geometry with plate and irradiator holders.
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2015-12-08 Some error in last print was corrected
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2015-12-24 Doplneni dokumentace a vlozeni vzoroveho programu pro PWMLED01B.
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2016-01-07 odebrani vsech zaloznich souboru kicad_pcb ktere zpusobuji konflikty ze SVN. Byl pri tom pouzit nasledujici prikaz:
    find . -type f -iname \*.kicad_pcb-bak -print0 | xargs -0 svn rm --force
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2016-01-31 oprava navrhu breakout frame a pridani aplikacnich listu.
2016-02-04 Vytvoreni noveho modulu RJ45V01A. Navrh PCB pripraven ke kontrole.
2016-02-05 opetovne smazani zaloznich souboru:
    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
2016-02-17 uprava anemometru a vygenerovani dat pro vyrobu PCB
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2016-04-06 programovani testovaciho kodu pro prime pripojeni na SPI sbernici.
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2016-04-17 zmena chovani na cyklicky test smeru otaceni motoru.
2016-06-21 zvysena odolnost kodu proti chybe prenosu na SPI.
    --Thisline, and those below, will be ignored--
    M CLOCKMOT.py
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2019-04-30 Drzak PCB a senzoru
    [MRAKOMER4_HOLDER01A.scad, MRAKOMER4_HOLDER02A.scad]
2019-05-02 Editace drzaku
    [MRAKOMER4_HOLDER01A.scad, MRAKOMER4_HOLDER02A.scad, P_MRAKOMER4_HOLDER01A.scad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]
2019-05-02 Zmena prumeru
    [MRAKOMER4_HOLDER02A.scad, P_MRAKOMER4_HOLDER02A.stl]
2019-05-05 Úprava modelů.
    [MRAKOMER4_HOLDER01A.scad, MRAKOMER4_HOLDER02A.scad, P_MRAKOMER4_HOLDER01A.stl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]
2019-05-05 Editace drzaku senzoru
    [MRAKOMER4_HOLDER02A.scad, P_MRAKOMER4_HOLDER02B.stl]
2020-12-07 Popisek na PCB
    [popis.xlsx]
2020-12-17 Tvorba gkódu
    [P_MRAKOMER4_HOLDER03A.stl]
2020-12-25 úprava samolepek na PCB
    [Samolepka_PCB.xlsx]
